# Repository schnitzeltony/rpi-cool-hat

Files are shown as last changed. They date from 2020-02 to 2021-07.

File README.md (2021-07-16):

# rpi-cool-hat

* At least Raspberry Pi 4 makes additional cooling mandatory.
* Most cooling solutions (all but oil?) do not allow stacked HATs (and at least musicians do not accept built-in audio).

This KiCad project suggests a glue-PCB letting coolers and HATs live in peace:

3d-preview

RPi is connected left / HAT connected right / cooler's fan connected to pins in the back as (example pictures are 180°rotated):

real-life

**Note that the project:**

* was created by Kicad 5.1.5 as shipped by Fedora 30
* 's author is not a professional layouter - awaiting PRs/issues - teach me :grin:
* was tested with HifiBerry DAC Pro and Flatmax AudioInjector
* IS PROVIDED "AS IS", WITHOUT WARRANTY OF ANY KIND!

**If you want one:**

* drop [rpi-cool-hat.kicad_pcb](rpi-cool-hat.kicad_pcb) to a supplier of your choice
* if your supplier does not accept Kicad: clone this project, go through gerber and send that to your supplier.
  To get an idea of how to accomplish it might help to watch https://www.youtube.com/watch?v=ENmDnoKs2hM
* or visit https://aisler.net/p/IRBRWUAC. Note that the author has no relation to Aisler.
  It was chosen because their production was considered close at time and place of writing.

**Tips:**

* Start soldering with J1
* When using Ice Tower Cooler cables are a bit short. To get around: Unmount fan, rotate 90° clockwise and mount again. Be careful not to over-tighten screws!
* For Ice Tower Cooler noise can be reduced significantly by using 3.3V supply on J1 (as written in the handbook). With reduced voltage I never saw CPU temperature rising above 45°
* If space is limited one might want to use a 90° variant of J2: 90-degree

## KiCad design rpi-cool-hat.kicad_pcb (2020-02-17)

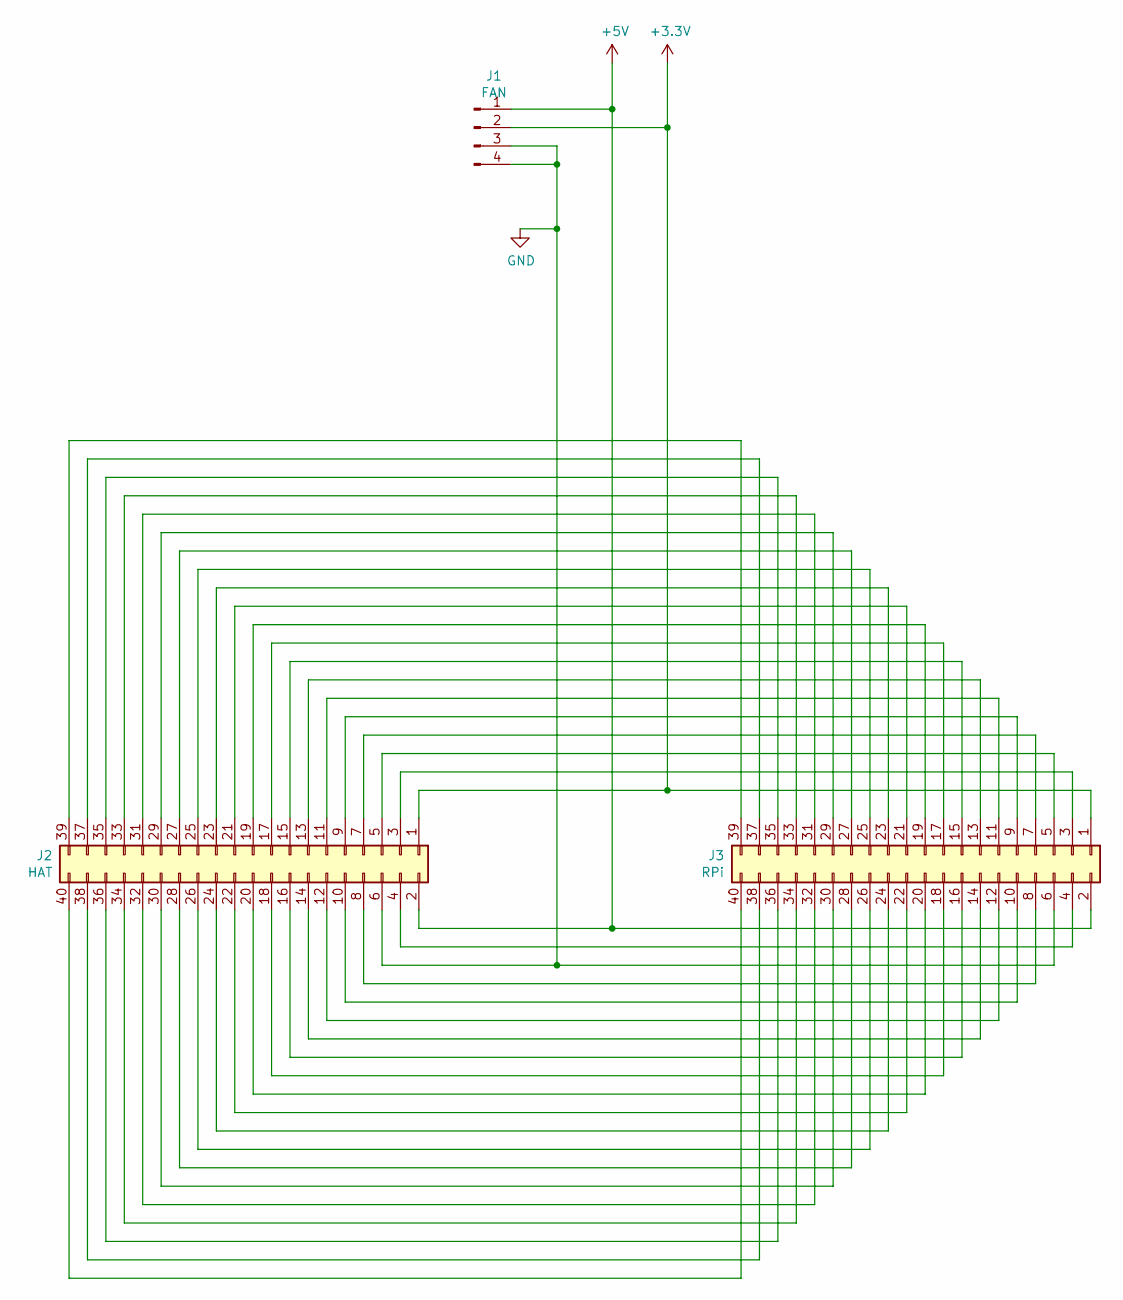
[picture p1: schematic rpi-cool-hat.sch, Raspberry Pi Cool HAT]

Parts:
J1: FAN; PinHeader_1x04_P2.54mm_Vertical
J2: HAT; PinHeader_2x20_P2.54mm_Vertical
J3: RPi; PinSocket_2x20_P2.54mm_Vertical

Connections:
+3V3: J1.2, J2.1, J3.1
+5V: J1.1, J2.2, J3.2
GND: J1.3, J1.4, J2.6, J3.6
unnamed: J2.3, J3.3
unnamed: J2.4, J3.4
unnamed: J2.5, J3.5
unnamed: J2.7, J3.7
unnamed: J2.8, J3.8
unnamed: J2.9, J3.9
unnamed: J2.10, J3.10
unnamed: J2.11, J3.11
unnamed: J2.12, J3.12
unnamed: J2.13, J3.13
unnamed: J2.14, J3.14
unnamed: J2.15, J3.15
unnamed: J2.16, J3.16
unnamed: J2.17, J3.17
unnamed: J2.18, J3.18
unnamed: J2.19, J3.19
unnamed: J2.20, J3.20
unnamed: J2.21, J3.21
unnamed: J2.22, J3.22
unnamed: J2.23, J3.23
unnamed: J2.24, J3.24
unnamed: J2.25, J3.25
unnamed: J2.26, J3.26
unnamed: J2.27, J3.27
unnamed: J2.28, J3.28
unnamed: J2.29, J3.29
unnamed: J2.30, J3.30
unnamed: J2.31, J3.31
unnamed: J2.32, J3.32
unnamed: J2.33, J3.33
unnamed: J2.34, J3.34
unnamed: J2.35, J3.35
unnamed: J2.36, J3.36
unnamed: J2.37, J3.37
unnamed: J2.38, J3.38
unnamed: J2.39, J3.39
unnamed: J2.40, J3.40

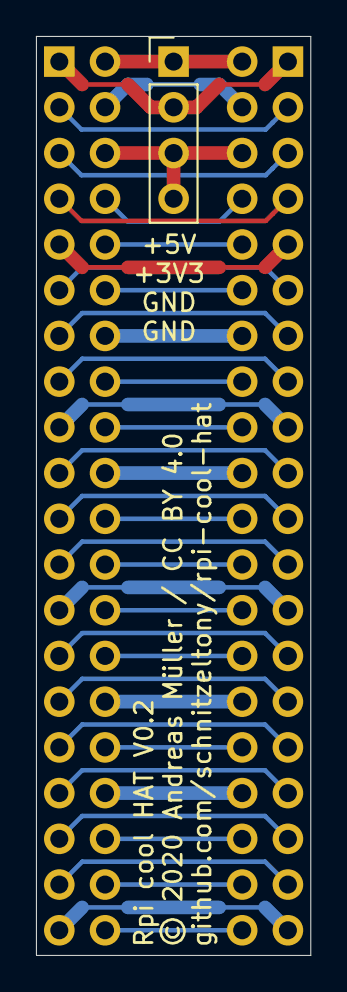
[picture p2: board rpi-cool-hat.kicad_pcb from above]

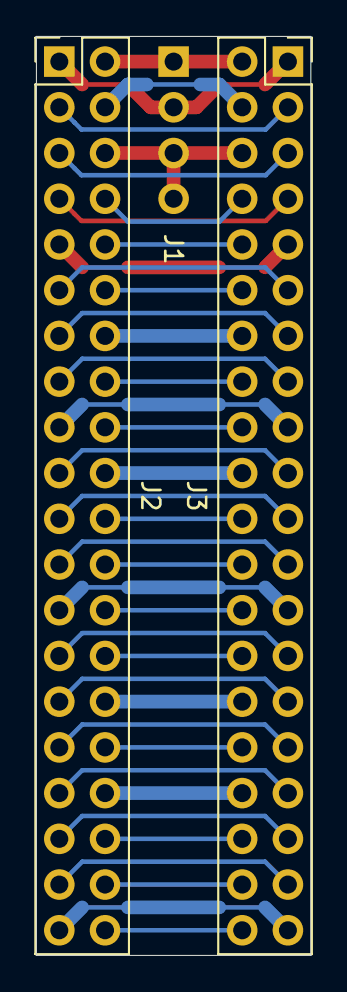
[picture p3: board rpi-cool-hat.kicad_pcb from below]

Board: 2 copper layers, 15.2 x 51.1 mm, 3 parts (2 on the bottom side), 40 nets.

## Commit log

2019-12-21 Thicken 5V @ pin 4
    [rpi-cool-hat.kicad_pcb]
2019-12-21 Rework Power/GND lines
    [rpi-cool-hat.kicad_pcb]
2019-12-22 PCB: minor fine tuning on lables and board dimension
    [rpi-cool-hat.kicad_pcb]
2019-12-22 PCB Show all layers
    [rpi-cool-hat.kicad_pcb]
2020-02-17 PCB: rework
    * Got puzzled with let and right. That caused fan connector pins connected at
    wrong pins.
    * Used 50mils for routing which caused cleaner layout
    * Reduced PCB size
    [rpi-cool-hat.kicad_pcb]

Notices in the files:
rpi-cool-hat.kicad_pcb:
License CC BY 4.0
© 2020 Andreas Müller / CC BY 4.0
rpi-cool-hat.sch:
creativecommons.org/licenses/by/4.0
